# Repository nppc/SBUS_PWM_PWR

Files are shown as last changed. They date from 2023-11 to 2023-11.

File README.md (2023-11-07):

# SBUS to PWM converter with power switch

Mini board for an 1m DLG to control 4 PWM servos from SBUS receiver.

Additinal functionality included power switch (reed switch or button) and connection for boost DC/DC to get 5V from 1S battery.

In standby mode the board consumes only 0.3uA. It means that on 200mA battery the board can stay in standby more than 50 years.

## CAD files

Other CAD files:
Firmware/Keil 8051 v9.60.0 - Debug/src/main.OBJ
Firmware/Keil 8051 v9.60.0 - Debug/src/sbus.OBJ
Firmware/Keil 8051 v9.60.0 - Debug/src/InitDevice.OBJ
Firmware/Keil 8051 v9.60.0 - Debug/src/adc.OBJ
Firmware/Keil 8051 v9.60.0 - Debug/src/button.OBJ
Firmware/Keil 8051 v9.60.0 - Debug/src/gen.OBJ
Firmware/Keil 8051 v9.60.0 - Debug/src/Interrupts.OBJ

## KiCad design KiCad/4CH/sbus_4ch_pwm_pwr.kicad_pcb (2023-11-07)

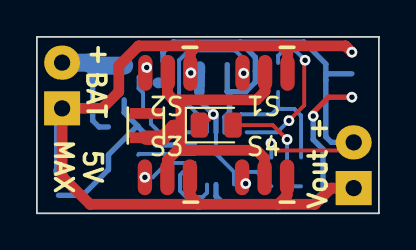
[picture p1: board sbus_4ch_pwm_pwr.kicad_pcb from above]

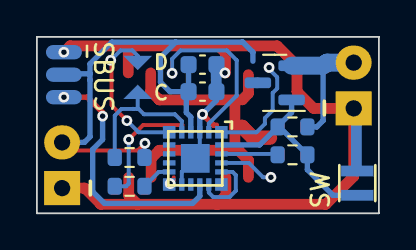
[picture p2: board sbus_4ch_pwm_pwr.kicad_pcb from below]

Board: 2 copper layers, 19.0 x 9.8 mm, 20 parts (12 on the bottom side), 16 nets.

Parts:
C1: 100n; C_0603_1608Metric
C2: 10uf; C_0603_1608Metric
D1: LED; LED_0805_2012Metric
J1: S2; Pads_prog_3pin1.25mm
J2: S1; Pads_prog_3pin1.25mm
J3: S3; Pads_prog_3pin1.25mm
J4: S4; Pads_prog_3pin1.25mm
J5: SBUS; Pads_prog_3pin1.25mm
J6: C2CK; RC_PAD_TRIANGLE
J7: C2D; RC_PAD_TRIANGLE
J8: BAT; Conn_1x02_2.54_0.9mm
J9: DC/DC; XFL2006-inductor
J10: SW; XFL2006-inductor
J11: PWR; Conn_1x02_2.54_0.9mm
Q1: AO3415; SOT-23
R1, R3: 4.7K; R_0603_1608Metric
R2: 100K; R_0603_1608Metric
R4: 560; R_0603_1608Metric
U1: EFM8BB51; QFN20

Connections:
+BATT: J8.2, Q1.2 (S), R2.1
/BUT_SENS: J10.2, Q1.1 (G), R2.2, R3.1, U1.20 (P0.2)
/C2CK: J6.1, R1.2, U1.5 (RSTb/C2CK)
/C2D: J7.1, U1.6 (P2.0/C2D)
/LED: R4.1, U1.10 (P1.3)
/MOSFET: R3.2, U1.19 (P0.3)
/PWM1: J2.3, U1.2 (P0.0)
/PWM2: J1.3, U1.1 (P0.1)
/PWM3: J3.3, U1.18 (P0.4)
/PWM4: J4.3, U1.11 (P1.2)
/SBUS: J5.3, U1.14 (P1.0)
GND: C1.2, C2.2, D1.1 (K), J1.1, J2.1, J3.1, J4.1, J5.1, J8.1, J10.1, J11.1, U1.3 (GND), U1.12 (GND), U1.21 (GND)
unnamed: D1.2 (A), R4.2
unnamed: U1.15 (P0.7), U1.17 (P0.5)
VBUS: C1.1, C2.1, J1.2, J2.2, J3.2, J4.2, J5.2, J9.2, J11.2, R1.1, U1.4 (VDD)
VDD: J9.1, Q1.3 (D)

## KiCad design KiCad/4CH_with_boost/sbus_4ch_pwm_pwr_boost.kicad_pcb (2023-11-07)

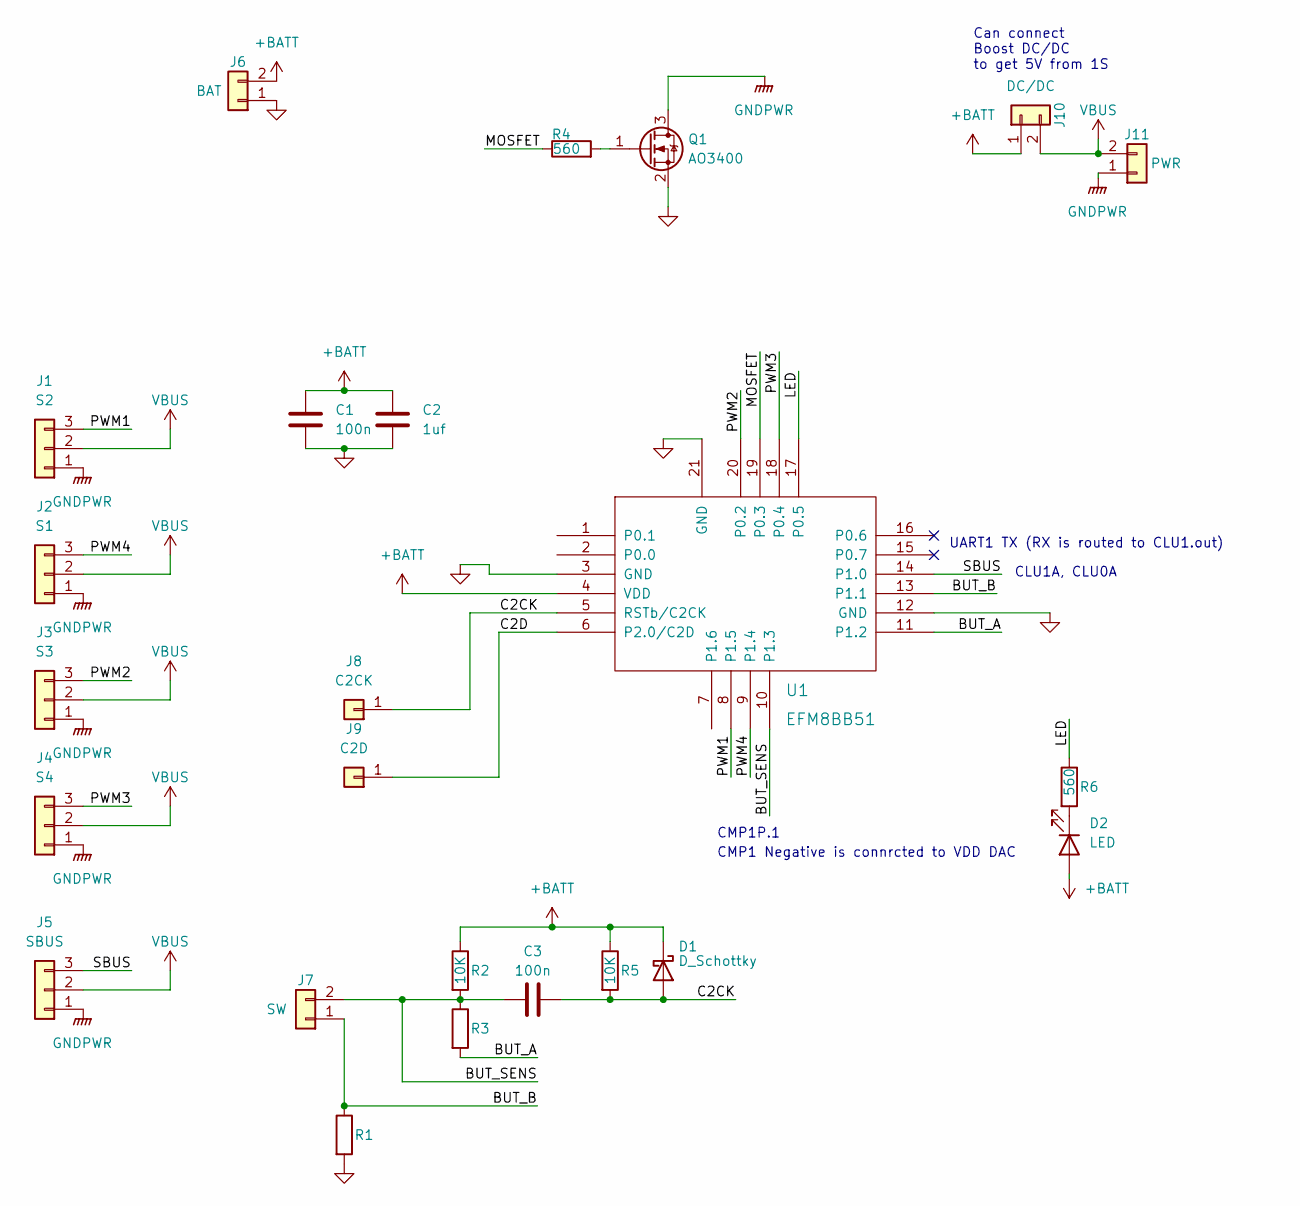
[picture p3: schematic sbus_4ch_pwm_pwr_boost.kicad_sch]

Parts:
C1, C3: 100n; C_0603_1608Metric
C2: 1uf; C_0603_1608Metric
D1: D_Schottky; D_SOD-523
D2: LED; LED_0805_2012Metric
J1: S2; Pads_prog_3pin1.25mm
J2: S1; Pads_prog_3pin1.25mm
J3: S3; Pads_prog_3pin1.25mm
J4: S4; Pads_prog_3pin1.25mm
J5: SBUS; Pads_prog_3pin1.25mm
J6: BAT; Conn_1x02_2.54_0.9mm
J7: SW; XFL2006-inductor
J8: C2CK; RC_PAD_TRIANGLE
J9: C2D; RC_PAD_TRIANGLE
J10: DC/DC; XFL2006-inductor
J11: PWR; PinHeader_1x02_P2.00mm_Vertical
Q1: AO3400; SOT-23
R1, R3: R_0603_1608Metric
R2, R5: 10K; R_0603_1608Metric
R4, R6: 560; R_0603_1608Metric
U1: EFM8BB51; QFN20

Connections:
+BATT: C1.1, C2.1, D1.1 (K), D2.2 (A), J6.2, J10.1, R2.1, R5.1, U1.4 (VDD)
/BUT_A: R3.2, U1.11 (P1.2)
/BUT_B: J7.1, R1.1, U1.13 (P1.1)
/BUT_SENS: C3.1, J7.2, R2.2, R3.1, U1.10 (P1.3)
/C2CK: C3.2, D1.2 (A), J8.1, R5.2, U1.5 (RSTb/C2CK)
/C2D: J9.1, U1.6 (P2.0/C2D)
/LED: R6.1, U1.17 (P0.5)
/MOSFET: R4.1, U1.19 (P0.3)
/PWM1: J1.3, U1.8 (P1.5)
/PWM2: J3.3, U1.20 (P0.2)
/PWM3: J4.3, U1.18 (P0.4)
/PWM4: J2.3, U1.9 (P1.4)
/SBUS: J5.3, U1.14 (P1.0)
GND: C1.2, C2.2, J6.1, Q1.2 (S), R1.2, U1.3 (GND), U1.12 (GND), U1.21 (GND)
GNDPWR: J1.1, J2.1, J3.1, J4.1, J5.1, J11.1, Q1.3 (D)
unnamed: D2.1 (K), R6.2
unnamed: Q1.1 (G), R4.2
VBUS: J1.2, J2.2, J3.2, J4.2, J5.2, J10.2, J11.2

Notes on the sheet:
UART1 TX (RX is routed to CLU1.out)
CMP1 Negative is connrcted to VDD DAC
Can connect Boost DC/DC to get 5V from 1S
CMP1P.1
CLU1A, CLU0A

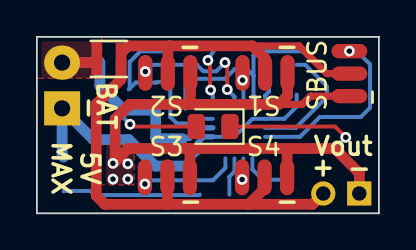
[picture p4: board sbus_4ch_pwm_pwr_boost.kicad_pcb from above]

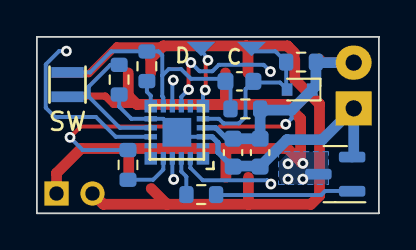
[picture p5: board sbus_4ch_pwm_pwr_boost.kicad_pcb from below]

Board: 2 copper layers, 19.0 x 9.8 mm, 24 parts (16 on the bottom side), 18 nets.

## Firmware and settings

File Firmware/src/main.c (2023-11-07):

//#pragma src
//-----------------------------------------------------------------------------
// Includes
//-----------------------------------------------------------------------------
#include "main.h"
#include "InitDevice.h"
#include "sbus.h"
#include "button.h"
#include "adc.h"

#define BUT_SENS_HIGH (CMP1CN0 & CMP1CN0_CPOUT__POS_GREATER_THAN_NEG)

volatile U16_U8 pwm_channels[4];
//volatile bit startup_reset;
volatile bit PWM_started = false;
volatile uint8_t delay_powering_counter;
volatile uint8_t led_pattern = 0, led_pattern_counter = 0;
// 0 - led off: Module is not powered
// 1 - led on: Module is powered
// 2 - fast blink: Module is in startup/shutdown process
// 3 - slow blink: After starting up indicates a low battery

volatile uint16_t timeout_counter = 0;
volatile bit timeout_tick = false;

//-----------------------------------------------------------------------------
// SiLabs_Startup() Routine
// ----------------------------------------------------------------------------
// This function is called immediately after reset, before the initialization
// code is run in SILABS_STARTUP.A51 (which runs before main() ). This is a
// useful place to disable the watchdog timer, which is enable by default
// and may trigger before main() in some instances.
//-----------------------------------------------------------------------------
void SiLabs_Startup(void) {

}

//-----------------------------------------------------------------------------
// main() Routine
// ----------------------------------------------------------------------------
int main(void) {

  enter_DefaultMode_from_RESET();

  PIN_MOSFET = false; // turn power mosfet off

  ADC0CN0_ADBUSY = true; // Start first conversion

  // PWM is disabled.

  IE_EA = true; //Enable interrupts

  // we wait for button to be pressed for at least 2 sec to ensure this is intended power on.
  led_pattern = 2; // fast blink
  delay_powering_counter = 0;
  while(delay_powering_counter<125){
      //if (BUT_SENS_HIGH && delay_powering_counter>50) goPowerDown(); // if button released too early
      PCON0 |= PCON0_CPUIDLE__BMASK; // go to IDLE
      PCON0 = PCON0; // ... followed by a 3-cycle dummy instruction
  }

  led_pattern = 1; // LED ON
  while(!BUT_SENS_HIGH); // wait until button is released
  waitNms(100); // wait for debounce

  PIN_MOSFET = true; // turn on power mosfet

  set_button_active();
  // now button behavior is reversed
  waitNms(100); // wait for new button levels stabilize

  while(1){
      // Power down if button pressed
      if(BUT_SENS_HIGH) { // Power button is pressed
          if(led_pattern != 2){
              led_pattern = 2; // fast blink
              delay_powering_counter = 0; // start counter for power off
          }
          if (delay_powering_counter>125) {
              led_pattern = 0; // LED OFF
              while(BUT_SENS_HIGH); // wait until button is released
              waitNms(100);
              goPowerDown(); // go power down
          }
      }else if(led_pattern == 2) led_pattern = 1; // restore led pattern

      if(sbus_packet_received){
          // check pack validity (secondary check)
          uint8_t tmp = sbus_packet[0];
          sbus_packet_received = false;
          if(sbus_parse()){
              // packet is well received
              uint16_t tmp;
              timeout_counter = 0;
              // convert sbus data to PWM and map channels to output
              tmp = convert_sbus_2_pwm(sbus_ch[1]);
              IE_EA = false;
              pwm_channels[0].u16 = tmp;
              IE_EA = true;
              tmp = convert_sbus_2_pwm(sbus_ch[2]);
              IE_EA = false;
              pwm_channels[1].u16 = tmp;
              IE_EA = true;
              tmp = convert_sbus_2_pwm(sbus_ch[3]);
              IE_EA = false;
              pwm_channels[2].u16 = tmp;
              IE_EA = true;
              tmp = convert_sbus_2_pwm(sbus_ch[0]);
              IE_EA = false;
              pwm_channels[3].u16 = tmp;
              IE_EA = true;

              if(!PWM_started){
                  PWM_started = true;
                  PCA0POL = PCA0POL_CEX0POL__INVERT | PCA0POL_CEX1POL__INVERT;
              }
          }
      }

      // check for timeout
      if(timeout_tick){
          timeout_tick = false;
          timeout_counter++;
          if(timeout_counter>3760){ // about 60 seconds
              // going power down due to no signal from transmitter
              led_pattern = 2; // fast blink
              delay_powering_counter = 0;
              while(delay_powering_counter < 50);
              goPowerDown();
          }
      }

      // check voltage
      if(isVoltageLow() && led_pattern !=2) led_pattern = 3;
  }

}

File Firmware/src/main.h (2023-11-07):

#include <SI_EFM8BB51_Register_Enums.h>                  // SFR declarations
#include <SI_EFM8BB51_Defs.h>
#include <stdint.h>

#ifndef MAIN_H_
#define MAIN_H_


// Structure for accessing 16bit number by 2 8 bit (back and forth)
// Usage:
// U16_U8 ptr;
// ptr.u8[0] = high;
// ptr.u8[1] = low;
// ptr.u16 = 16bit;
typedef union
   {
   unsigned short u16;
   unsigned char u8[2];
   } U16_U8;

extern void waitNms(uint16_t ms);
extern uint16_t convert_sbus_2_pwm(uint16_t val);
extern void goPowerDown(void);
extern bit isVoltageLow(void);

//SI_SBIT(PIN_PWM1, SFR_P1, 5); // TSSOP-20 PIN10
//SI_SBIT(PIN_PWM2, SFR_P0, 2); // TSSOP-20 PIN2
//SI_SBIT(PIN_PWM3, SFR_P0, 4); // TSSOP-20 PIN20
//SI_SBIT(PIN_PWM4, SFR_P1, 4); // TSSOP-20 PIN11
//SI_SBIT(PIN_SBUS, SFR_P1, 0); // TSSOP-20 PIN16
SI_SBIT(PIN_LED, SFR_P0, 5);  // TSSOP-20 PIN19
SI_SBIT(PIN_MOSFET, SFR_P0, 3); // TSSOP-20 PIN1
SI_SBIT(PIN_BUTA, SFR_P1, 2); // TSSOP-20 PIN13
SI_SBIT(PIN_BUTB, SFR_P1, 1); // TSSOP-20 PIN15
SI_SBIT(PIN_BUT_SENS, SFR_P1, 3); // TSSOP-20 PIN12
// CLU1A TSSOP-20 PIN 16


extern U16_U8 pwm_channels[];
extern bit PWM_started;
extern uint8_t delay_powering_counter;
extern uint8_t led_pattern, led_pattern_counter;
extern uint16_t timeout_counter;
extern bit timeout_tick;

#endif /* MAIN_H_ */
